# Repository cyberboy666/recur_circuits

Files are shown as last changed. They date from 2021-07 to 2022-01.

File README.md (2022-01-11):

# recur_circuits (archived)
was a collection of extension circuits for [r_e_c_u_r](https://github.com/cyberboy666/r_e_c_u_r) video sampler

these projects have been moved to their own repos:

- [i_n_c_u_r](https://github.com/cyberboy666/i_n_c_u_r) - adding knobs, cv and serial midi control
- [c_l_i_k_r](https://github.com/cyberboy666/c_l_i_k_r) - custom keypad/midi controller
- NEO_RECUR - still a WIP; watch this space

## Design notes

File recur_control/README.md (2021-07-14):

# recur control circuit

this is a lil circuit that aims to offer a low-cost alternative to using cheapo plastic numpads to control recur. when i first designed recur i decided to use [these](https://www.aliexpress.com/item/4000748567192.html) numpads from aliexpress. my main goals at the time were making the project as simple and accessable as possible. however over the last few years many people have had problems using (possible variations?) of these numpads and others. seemingly similar devices run conflicting firmware, different layout of keys on different versions, crashes, gross hacks needed in the code, partial working units, and many more frustrating problems that are impossible for me to debug without owning every differnet device. i am also aware of contributing to the consumption of ecologically and ethically problematic products by endorsing these devices..

alsonow that recur has evolved beyond just a sample-player, having continuous control over parameters (like shaders) is more important than it was before. still one of the best options is to use a korg-nano-kontrol or similar midi controller as this gives many faders to control effects with. however for people who dont have a nanokontrol or want to use it elsewhere in their setup, i have been thinking of a small cheap and simple alterative to using numpads:



- 20x tac-switches for discrete control
- (optional) 4x pot + 4x cv for continuous control
- firmware can be set to act as midi device (required for cc ) or keyboard device
- shouldnt come to much more than 10€ cost in parts (ofcourse more for kits/assembled if i ever get round to this)

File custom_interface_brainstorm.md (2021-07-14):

# custom recur interface brainstorm

how best to have an 'all-in-one' recur unit.

## some general thoughts:

- thinking of using mechanical keys, like the [cherry](https://www.mouser.de/ProductDetail/CHERRY/MX1A-E1NW?qs=Z7NFYKyvgJd45Wm4xzFv7w%3D%3D) form factor
- posibilty of using  rotarty encoders (i would go for the same [type](https://www.mouser.de/ProductDetail/Bourns/PEC11R-4220F-S0024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) as on o_C - with built in switches )
- having some knobs for shader/param control ? (best would be 12-16 like on nanokontrl but even 4 could be good)
- also include cv ins here -> best would be if the knobs also antunated this cv (so bit more complex circuit - using opamps) - also wondering if 0-5v range is ok or something else is better ? 0-1v? -12/+12v - since pi power is 5v may complecate the power situation to work outside of this range...
- do we want serial midi input here also ?
- do we want all interface parts vertical mounted/ front facing for easier mounting in euro cases ? (keeping in mind that tssr/hdmi/usb ports of pi are not front facing anyway) or so we also add some more horizontal inputs around these ?
- in general what dimensions should we be looking at ? main reason i havnt designed something like this before is getting pcbs that are larger than 100x100cm have been quite costly. this is not so much the case now days with jlcpcb - you can get quotes based on boardsize on [their](https://cart.jlcpcb.com/quote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) site. here 10x 150mmx150mm comes to ~$16 +shipping... not bad ?

## technical thoughts:

- should these control parts (switches/pots/cv/midi/encoder) connect directly to the gpio of the rpi (this is how the incur/recurboy circuits do it) or should they be merged through a microcontroller and send to pi through a consistant protocol ? (this is how the custom keypad idea will it)
- problem with the direct connection is it tends to get a bit messy, uses many different gpio pins and having differnt input types in the recur code can be bit annoying/confusing...
- if going for unified approach, this will add micro-controller to the board - need to decide on a form-factor for this. also to decide on the protocol. midi could be good since already implemented... main problem with this is only 7bit resolution on the cc ins. maybe could look into supporting midi2 ? or i know that some monome instruments are using an [i2c protocol](https://llllllll.co/t/a-users-guide-to-i2c/19219) -> could be worth looking into this (for examole teh 16n faderbank supports this) or define a custom (serial?) protocol? or use less signifacant bit/ approach for midi ?

## how to upload an image to a github document

brainstorms like this are best with lots of images. github allows image uploads in a roundabout way. heres how to do it:

- create a new issue in another tab (or enter a new one)
- paste the image you want to use into the text field of this issue
- copy the link this generates and paste into the document
- now use _preview change_ tab to see this image in the document

for example - [video example](https://videos.scanlines.xyz/videos/watch/d79c4667-a746-4e0c-8e62-49e23e37e957):



# first mockup

heres a test modelling what this could look like (mainly to test all the related 3d models i imported) , inpired partly by the blackbox shape (although to be fair this is a pretty common/ obvious choice of layout - not much different from the orginal recur/incur layouts,,)



- 4x encoders with switch
- 12x cherrymx buttons
- 4x small press buttons
- 4x cv inputs + 1x midi input
- room for the circuitry underneath the pi-screen
- rpi attached on bottom of pcb -> room to plug usb / power / vidoe out etc
- dimensions are 120x120mm technically possilbe to rack it in 24hp (maybe racking the pcb itself so it protudes?) but less useful due to acces to pi controls



this is just a draft to get the ball/ conversation rolling - open to other sujections / ideas

# small update



- decided to try interfacing directly to the pi gpio first (see how this is - only fall back on the 'microcontroller' option if needed...)
- seeing if labels on the pcb would be readable / useful or if they need to be on a front panel, or if they need to be on the caps somehow ? (labels are made up things not real recur functions)

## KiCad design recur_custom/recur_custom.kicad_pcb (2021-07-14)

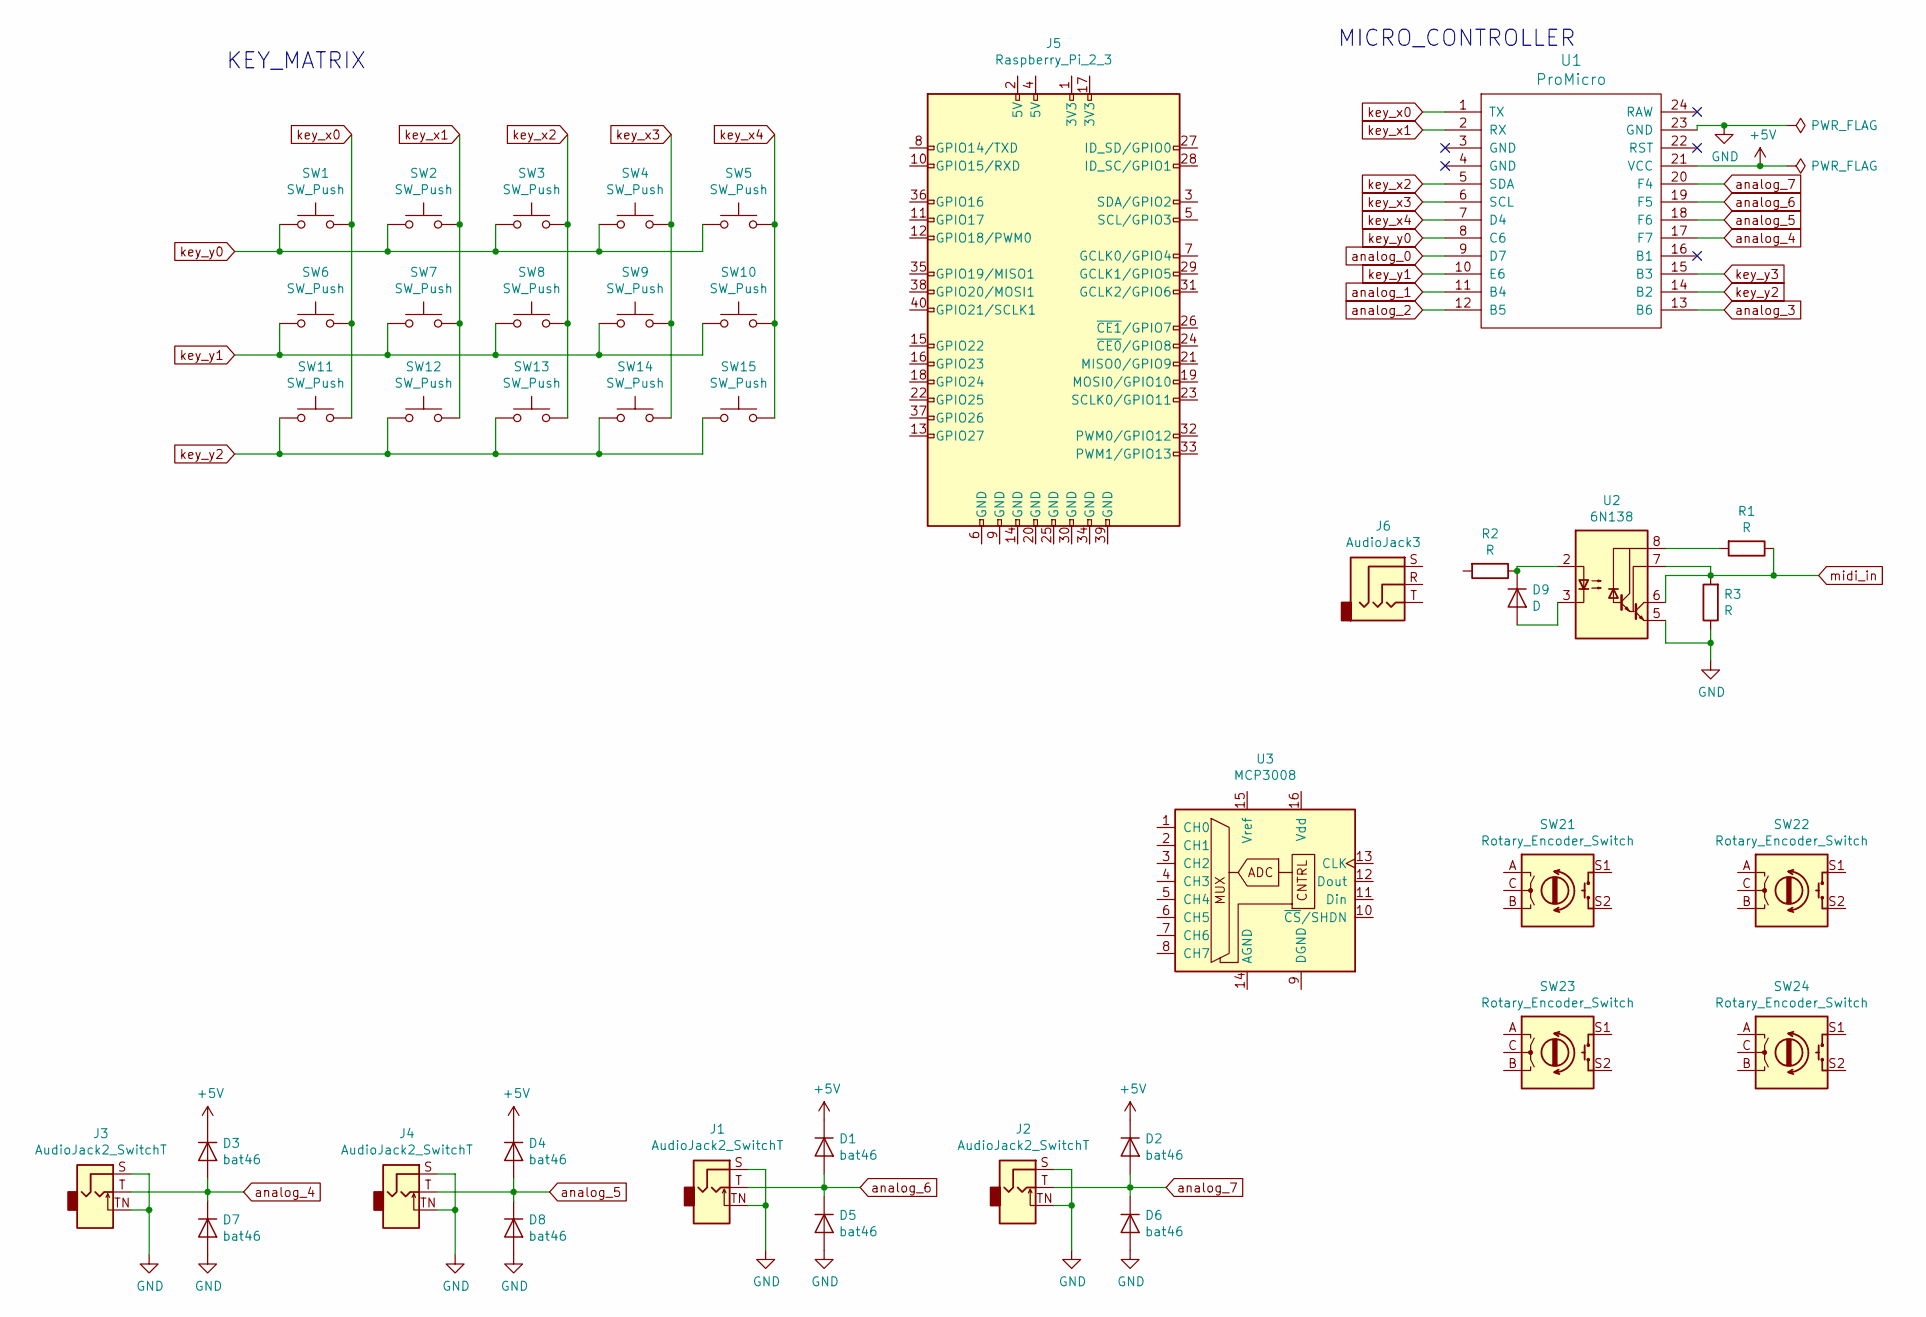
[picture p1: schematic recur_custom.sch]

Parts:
D1, D2, D3, D4, D5, D6, D7, D8: bat46; D_DO-34_SOD68_P7.62mm_Horizontal
D9: D; D_DO-34_SOD68_P7.62mm_Horizontal
J1, J2, J3, J4: AudioJack2_SwitchT; Tayda_3.5mm_stereo_TRS_jack_A-853
J5: Raspberry_Pi_2_3; MODULE_RASPBERRYPI4_4GB
J6: AudioJack3; Tayda_3.5mm_stereo_TRS_jack_A-853
R1, R2, R3: R; R_Axial_DIN0207_L6.3mm_D2.5mm_P5.08mm_Vertical
SW1, SW2, SW3, SW4, SW5, SW6, SW7, SW8, SW9, SW10, SW11: SW_Push; SW_Cherry_MX_1.00u_PCB
SW12, SW13, SW14, SW15: SW_Push; SW_PUSH_6mm_H7.3mm
SW21, SW22, SW23, SW24: Rotary_Encoder_Switch; RotaryEncoder_Alps_EC11E-Switch_Vertical_H20mm_CircularMoun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
U1: ProMicro
U2: 6N138; DIP-8-16_W7.62mm
U3: MCP3008; DIP-16_W7.62mm

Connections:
+5V: D1.1 (K), D2.1 (K), D3.1 (K), D4.1 (K), U1.21 (VCC)
GND: D5.2 (A), D6.2 (A), D7.2 (A), D8.2 (A), J1.S, J1.TN, J2.S, J2.TN, J3.S, J3.TN, J4.S, J4.TN, R3.1, U1.23 (GND), U2.5 (GND)
unnamed: D9.1 (K), R2.1, U2.2 (C1)
unnamed: D9.2 (A), U2.3 (C2)
unnamed: R1.2, U2.8 (VCC)
analog_0: U1.9 (D7)
analog_1: U1.11 (B4)
analog_2: U1.12 (B5)
analog_3: U1.13 (B6)
analog_4: D3.2 (A), D7.1 (K), J3.T, U1.17 (F7)
analog_5: D4.2 (A), D8.1 (K), J4.T, U1.18 (F6)
analog_6: D1.2 (A), D5.1 (K), J1.T, U1.19 (F5)
analog_7: D2.2 (A), D6.1 (K), J2.T, U1.20 (F4)
key_x0: SW1.2, SW6.2, SW11.2, U1.1 (TX); also elsewhere on the board
key_x1: SW2.2, SW7.2, SW12.2, U1.2 (RX)
key_x2: SW3.2, SW8.2, SW13.2, U1.5 (SDA)
key_x3: SW4.2, SW9.2, SW14.2, U1.6 (SCL); also elsewhere on the board
key_x4: SW5.2, SW10.2, SW15.2, U1.7 (D4)
key_y0: SW1.1, SW2.1, SW3.1, SW4.1, SW5.1, U1.8 (C6)
key_y1: SW6.1, SW7.1, SW8.1, SW9.1, SW10.1, U1.10 (E6)
key_y2: SW11.1, SW12.1, SW13.1, SW14.1, SW15.1, U1.14 (B2)
key_y3: U1.15 (B3); also elsewhere on the board
midi_in: R1.1, R3.2, U2.6 (VO2), U2.7 (VO1)

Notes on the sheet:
KEY_MATRIX
MICRO_CONTROLLER

Board: 2 copper layers, 40 parts (0 on the bottom side), 17 nets, no tracks yet.

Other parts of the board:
SW16, SW19: SW_Push; SW_Cherry_MX_1.00u_PCB

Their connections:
key_x0: SW16.2; also elsewhere on the board
key_x3: SW19.2; also elsewhere on the board
key_y3: SW16.1, SW19.1; also elsewhere on the board

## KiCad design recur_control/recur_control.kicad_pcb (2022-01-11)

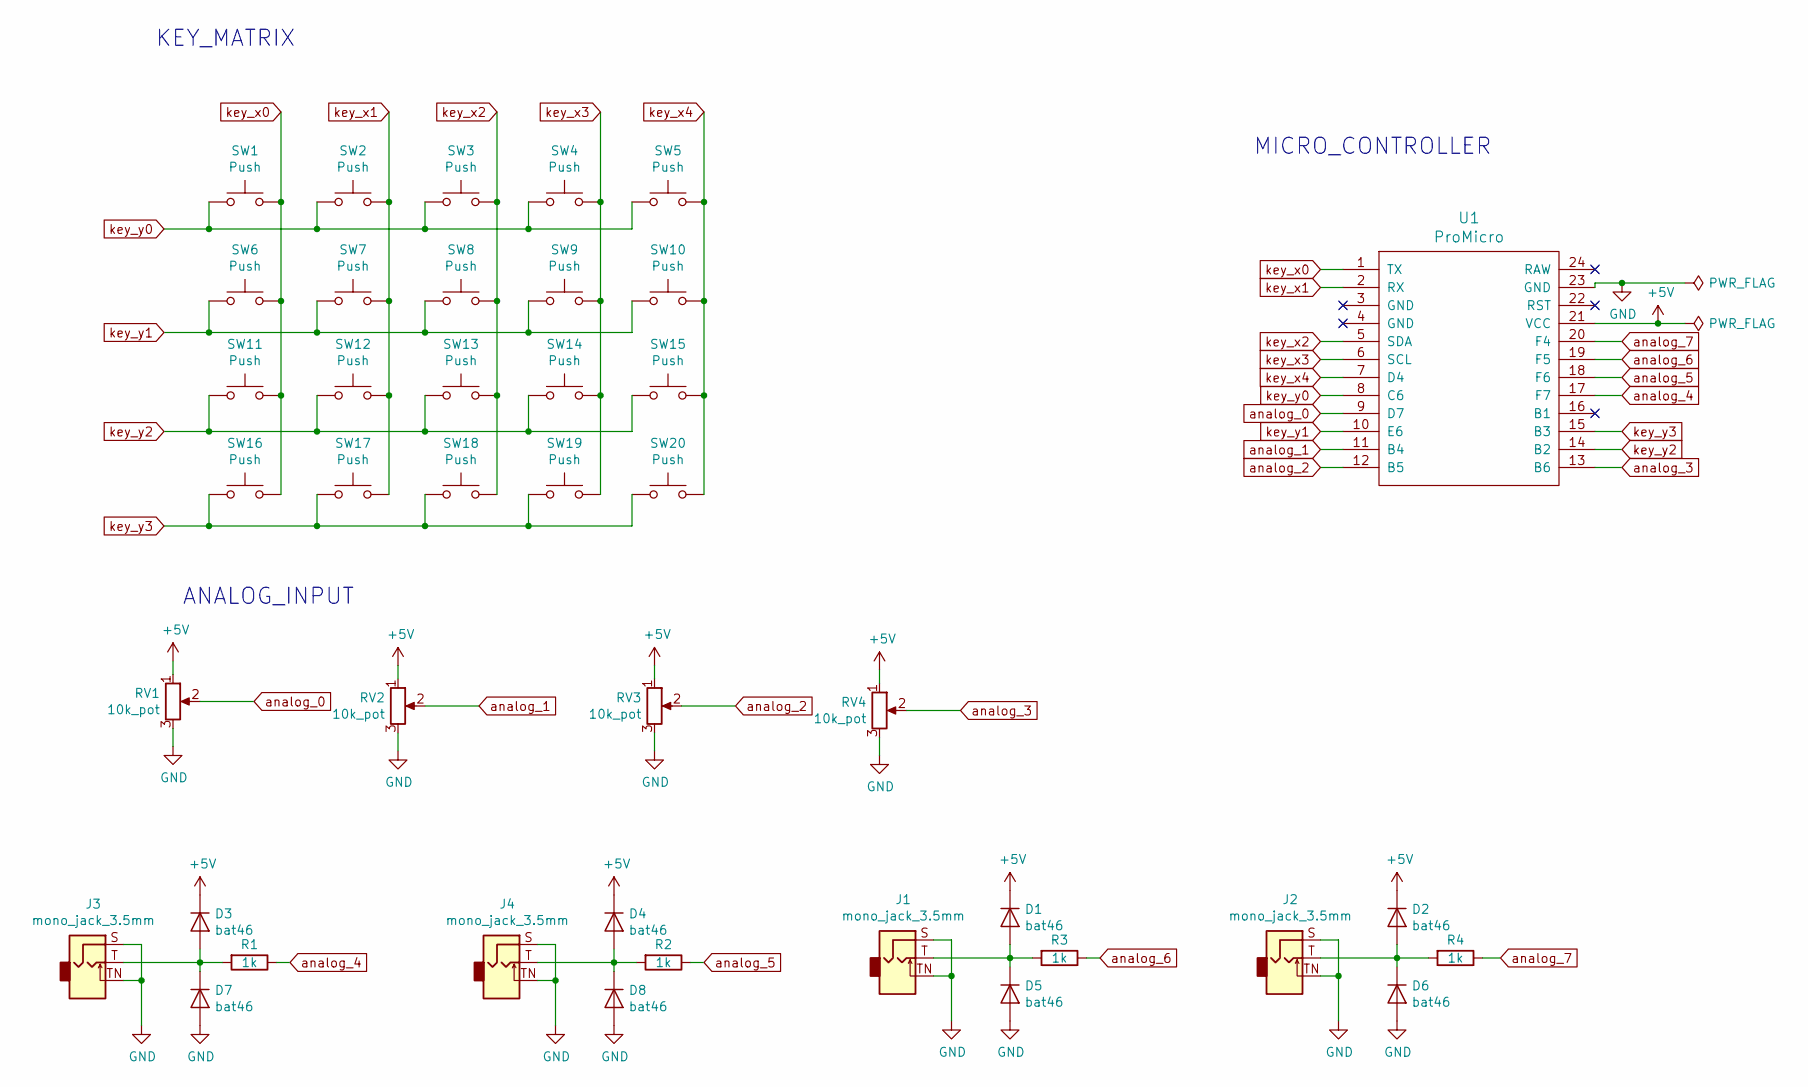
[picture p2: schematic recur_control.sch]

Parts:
D1, D2, D3, D4, D5, D6, D7, D8: bat46; D_DO-34_SOD68_P7.62mm_Horizontal
J1, J2, J3, J4: mono_jack_3.5mm; Jack_3.5mm_QingPu_WQP-PJ398SM_Vertical_CircularHoles
R1, R2, R3, R4: 1k; R_Axial_DIN0207_L6.3mm_D2.5mm_P7.62mm_Horizontal
RV1, RV2, RV3, RV4: 10k_pot; Potentiometer_Alps_RK09L_Single_Vertical
SW1, SW2, SW3, SW4, SW5, SW6, SW7, SW8, SW9, SW10, SW11, SW12, SW13, SW14, SW15, SW16, SW17, SW18, SW19, SW20: Push; SW_PUSH_6mm_H7.3mm
U1: ProMicro

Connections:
+5V: D1.1 (K), D2.1 (K), D3.1 (K), D4.1 (K), RV1.1, RV2.1, RV3.1, RV4.1, U1.21 (VCC)
GND: D5.2 (A), D6.2 (A), D7.2 (A), D8.2 (A), J1.S, J1.TN, J2.S, J2.TN, J3.S, J3.TN, J4.S, J4.TN, RV1.3, RV2.3, RV3.3, RV4.3, U1.23 (GND)
unnamed: D1.2 (A), D5.1 (K), J1.T, R3.2
unnamed: D2.2 (A), D6.1 (K), J2.T, R4.2
unnamed: D3.2 (A), D7.1 (K), J3.T, R1.2
unnamed: D4.2 (A), D8.1 (K), J4.T, R2.2
analog_0: RV1.2, U1.9 (D7)
analog_1: RV2.2, U1.11 (B4)
analog_2: RV3.2, U1.12 (B5)
analog_3: RV4.2, U1.13 (B6)
analog_4: R1.1, U1.17 (F7)
analog_5: R2.1, U1.18 (F6)
analog_6: R3.1, U1.19 (F5)
analog_7: R4.1, U1.20 (F4)
key_x0: SW1.2, SW6.2, SW11.2, SW16.2, U1.1 (TX)
key_x1: SW2.2, SW7.2, SW12.2, SW17.2, U1.2 (RX)
key_x2: SW3.2, SW8.2, SW13.2, SW18.2, U1.5 (SDA)
key_x3: SW4.2, SW9.2, SW14.2, SW19.2, U1.6 (SCL)
key_x4: SW5.2, SW10.2, SW15.2, SW20.2, U1.7 (D4)
key_y0: SW1.1, SW2.1, SW3.1, SW4.1, SW5.1, U1.8 (C6)
key_y1: SW6.1, SW7.1, SW8.1, SW9.1, SW10.1, U1.10 (E6)
key_y2: SW11.1, SW12.1, SW13.1, SW14.1, SW15.1, U1.14 (B2)
key_y3: SW16.1, SW17.1, SW18.1, SW19.1, SW20.1, U1.15 (B3)

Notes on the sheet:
KEY_MATRIX
ANALOG_INPUT
MICRO_CONTROLLER

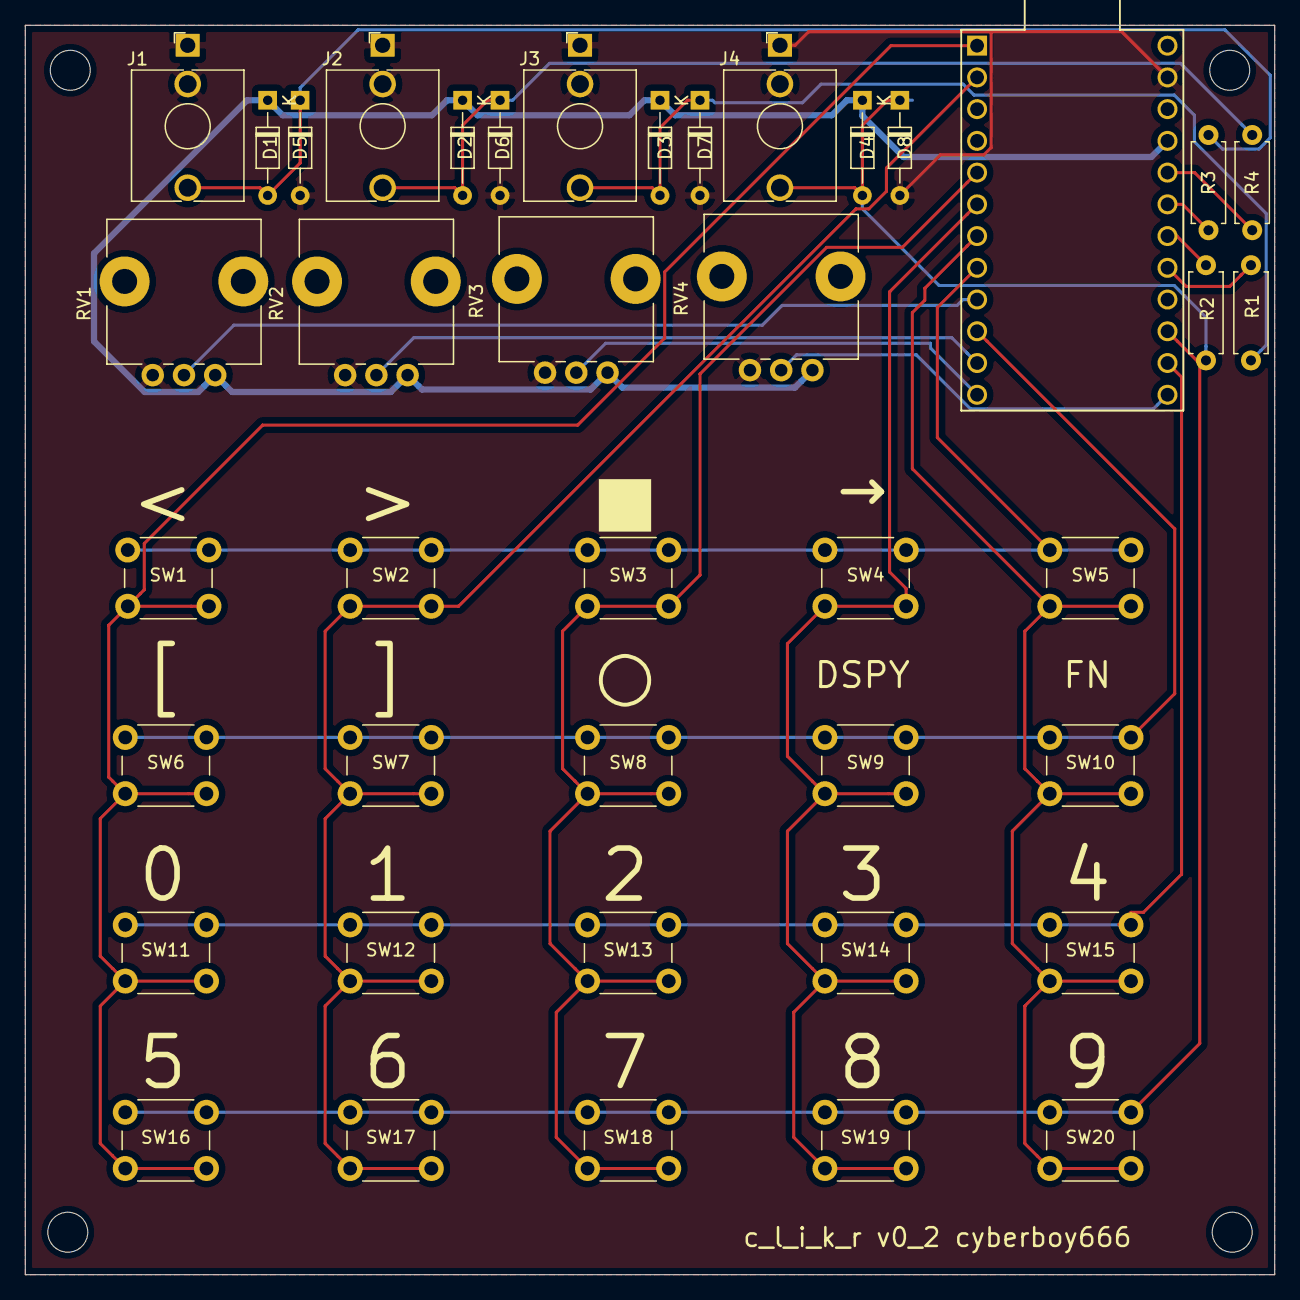
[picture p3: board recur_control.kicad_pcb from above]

Board: 2 copper layers, 100.0 x 100.0 mm, 41 parts (0 on the bottom side), 23 nets.

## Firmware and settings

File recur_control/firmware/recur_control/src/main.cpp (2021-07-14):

#include <Arduino.h>
#include <Keypad.h>

const byte ROWS = 4; //five rows
const byte COLS = 5; //four columns
char keys[ROWS][COLS] = {
  {'a', 'b', 'c', 'd', 'x'},
  {'e', 'f', 'g', 'h', 'i'},
  {'j', 'k', 'l', 'm', 'n'},
  {'o', 'p', 'q', 'r', 's'}
};
byte rowPins[ROWS] = {5, 7, 16, 14}; //connect to the row pinouts of the keypad
byte colPins[COLS] = {1, 0, 2, 3, 4}; //connect to the column pinouts of the keypad

Keypad keypad = Keypad( makeKeymap(keys), rowPins, colPins, ROWS, COLS );

int a0 = A7;
int a1 = A8;
int a2 = A9;
int a3 = A10;
int a4 = A0;
int a5 = A1;
int a6 = A2;
int a7 = A3;

int v0, v1, v2, v3, v4, v5, v6, v7;

void setup() {
  // put your setup code here, to run once:
  Serial.begin(9600);
}

void loop() {
  // put your main code here, to run repeatedly:
  char key = keypad.getKey();



  if (key != NO_KEY){
    v0 = analogRead(a0);
    v1 = analogRead(a1);
    v2 = analogRead(a2);
    v3 = analogRead(a3);
    v4 = analogRead(a4);
    v5 = analogRead(a5);
    v6 = analogRead(a6);
    v7 = analogRead(a7);

    Serial.println(key);
    Serial.println(v0);
    Serial.println(v1);
    Serial.println(v2);
    Serial.println(v3);
    Serial.println(v4);
    Serial.println(v5);
    Serial.println(v6);
    Serial.println(v7);
  }
}

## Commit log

2020-10-21 add recur control circuit
    [recur_control.kicad_pcb, recur_control.sch]
2021-07-14 clikr circuit revision and start of code
    [recur_control-B_Cu.gbr, recur_control-B_Mask.gbr, recur_control-B_Paste.gbr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]
2022-01-11 add brainstorm for new recur design
    [recur_control-B_Cu.gbr, recur_control-B_Mask.gbr, recur_control-B_Paste.gbr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]
